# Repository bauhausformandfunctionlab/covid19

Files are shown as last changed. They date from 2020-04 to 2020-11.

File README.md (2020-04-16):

**Bauhaus Form + Function Lab**<br />
**Community Resources for COVID-19**<br />
**https://bffl.io**<br />

As the world works together to overcome the unprecedented challenges brought on by the COVID-19 pandemic, the team at the [Bauhaus Form + Function Lab](https://uni-weimar.de/bffl) is currently working with [partners and collaborators](http://bffl.io/partners) across the region and across Europe to share relevant designs and optimizations for personal hygiene equipment and other materials, which can be produced with the standard tools found in prototype labs, fablabs, makerspaces and individual studios in communities around the globe.

The Fine Print: We strongly urge everyone to adhere to the strictest hygiene measures and to consult with local authorities before beginning production or distribution. While these designs are being shared in good faith, the BFFL and Bauhaus-Universität Weimar do not guarantee the suitability for use, merchantability, or fitness for particular purpose of the designs listed below, and do not assume liability arising from their production or use. These designs are presented as research for individual experimentation and are not intended for production or use as medical products. The production and use of these designs is at your own risk. Please be aware that designs below are the property of their respective creators and are protected by various open source licenses. Feel free to share the resources linked here with other partners and institutions.

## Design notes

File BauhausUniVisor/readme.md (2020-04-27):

**Production Files for the BauhausUniVisor**<br />
Co-developed by Prof. Andreas Mühlenberend & Vertr.-Prof. Jason Reizner<br />
Production optimizations by Kristian Gohlke<br />
Bauhaus-Universität Weimar<br />
[https://bffl.io](https://bffl.io)

one material<br />
one process<br />
one minute<br />

#bauhausunivisor<br />
#oneminutevisor

This work is licensed under a [Creative Commons Attribution-NonCommercial-ShareAlike 4.0 International License](https://creativecommons.org/licenses/by-nc-sa/4.0/) and can be used for non-commercial purposes. Get in touch with the team if you would like to manufacture larger quantities under individual conditions.

**MAIN PRODUCTION FILE:**<br />
[BauhausUniVisor_2020_04_16_VARIANT_A_and_VARIANT_B_combined_NO_BRIDGES.pdf](https://github.com/bauhausformandfunctionlab/covid19/blob/master/BauhausUniVisor/BauhausUniVisor_2020_04_16_VARIANT_A_and_VARIANT_B_combined_NO_BRIDGES.pdf)

**PRINT these Files and distribute them with the Visors**<br />
Important Notes ('Beipackzettel', German):
[BauhausUniVisor_Beipackzettel_DE.pdf](https://github.com/bauhausformandfunctionlab/covid19/blob/master/BauhausUniVisor/BauhausUniVisor_Beipackzettel_DE.pdf)<br />
Assembly Instructions / Montageanleitung:
[BauhausUniVisor_Assembly_Guide.pdf](https://github.com/bauhausformandfunctionlab/covid19/blob/master/BauhausUniVisor/BauhausUniVisor_Assembly_Guide.pdf)

**Assembly Video:**<br />
The BauhausUniVisor - COVID19 laser cut face shield // One material, One process, One minute (https://www.youtube.com/watch?v=4FKMDfHXxKk)

**HINWEIS:** Visiere sind **kein** Ersatz für eine Mund-Nasenbedeckung!<br />
**NOTE:** Face Shield Visors are **not** a replacement for cloth face coverings or surgical face masks!  

This visor is intended to be produced from 0.5mm PETG film. In situations where PETG is not available, PET film can be substituted when sufficient surface quality and optical clarity can be guaranteed.

With sufficient laser power and optimization, one visor can be cut in one minute.

For flat PETG sheets coated with protective film, cutting in two passes is recommended using the highest speed and lowest power settings possible. We are currently cutting in two passes on a 120W Epilog CO2 system at 100s/70p/50f with power compensation enabled.

For PET material from the roll, cutting in a single pass using the provided templates marked 'with BRIDGES' will ensure correct registration of the work pieces. Since this material generally is not coated with protective film, it is recommended to remove cutting residue using alcohol.

On a low-cost 40W Lasercutter (tested on Beambox Pro) we have achieved good results with uncoated PET from a roll, cutting in a single pass at 30mm/sec and 63% Power.

When laser cutting PETG or PET, a sufficient exhaust extractor and filter system is necessary.

Preliminary tests indicate that PETG is resistant to disinfection agents including isopropyl alcohol, quaternary ammonium compounds and hydrogen peroxide solution. Note: PET/PETG components are *not* dishwasher safe.

We strongly urge everyone to adhere to the strictest hygiene measures and to consult with local authorities before beginning production or distribution. 

While this design is being shared in good faith, the Bauhaus Form + Function Lab and Bauhaus-Universität Weimar do not guarantee the suitability for use, merchantability, or fitness for particular purpose of the this visor, and do not assume liability arising from their production or use. This design is not intended for production or use as a medical device.

This work is licensed under a Creative Commons Attribution-NonCommercial-ShareAlike 4.0 International License.

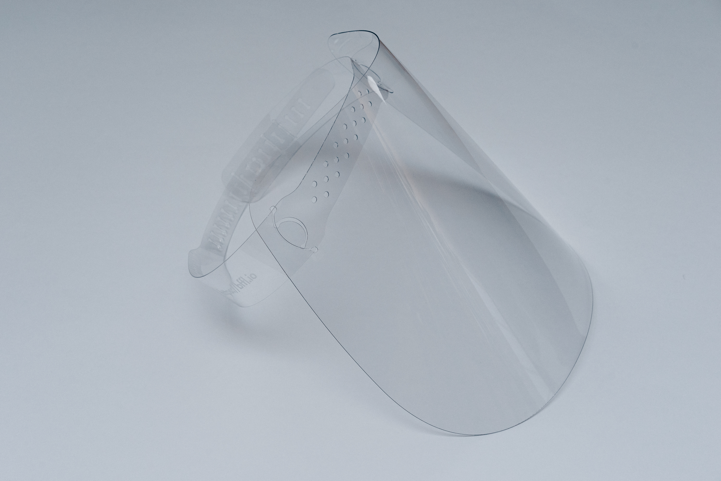
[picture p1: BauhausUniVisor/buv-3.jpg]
BauhausUniVisor


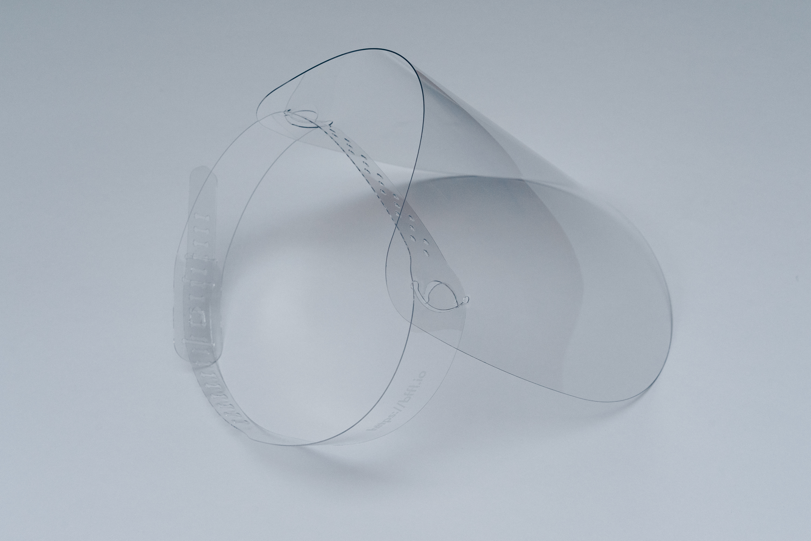
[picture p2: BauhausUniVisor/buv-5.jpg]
BauhausUniVisor


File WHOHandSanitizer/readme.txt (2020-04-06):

This is the directory for materials relating to the WHO Hand Sanitizer Formula.

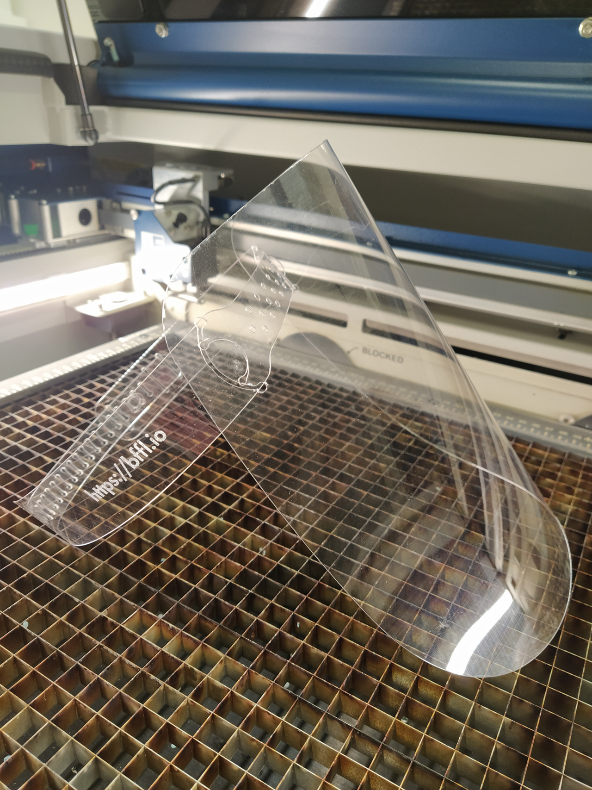
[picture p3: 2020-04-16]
BauhausUniVisor/BauhausUniVisor_Lasercut.jpg

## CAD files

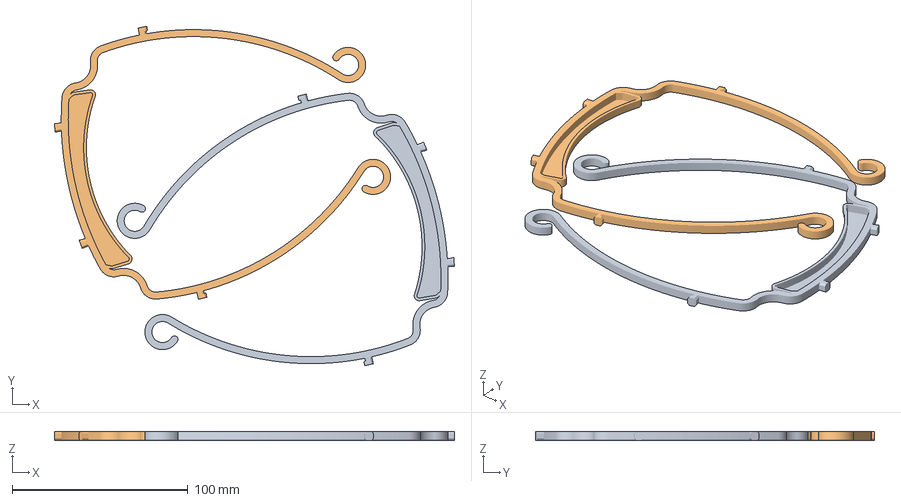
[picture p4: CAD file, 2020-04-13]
3DVerkstanVisor/2x_0.8_Visor_frame_EUROPE_ISO838_v3.3mf
227.4 x 193.0 x 5.00 mm
Visor_frame_EUROPE_ISO838_v3.stl x 2

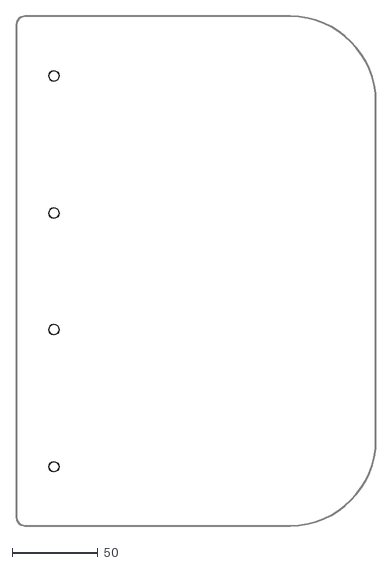
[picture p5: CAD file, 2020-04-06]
3DVerkstanVisor/ShieldTemplates/Lasercut-shield-EUROPE-ISO838-A6.dxf
210.0 x 297.0

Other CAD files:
alternative covid-19 production resources/3DVerkstanVisor/ShieldTemplates/Lasercut-shield-SWEDEN-A4.dxf
3DVerkstanVisor/ShieldTemplates/Lasercut-shield-SWEDEN-A4.dxf

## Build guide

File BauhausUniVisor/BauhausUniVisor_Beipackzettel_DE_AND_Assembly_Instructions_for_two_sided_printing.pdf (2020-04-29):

# BauhausUniVisor

# one material

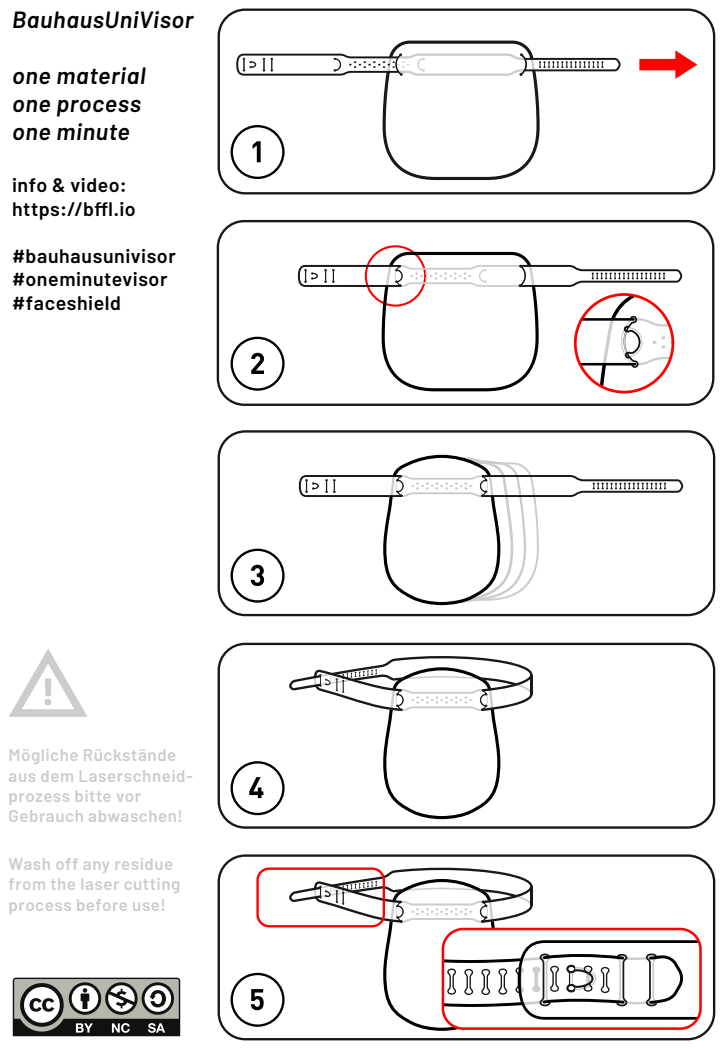
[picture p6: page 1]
one process one minute; info & video: https://b.io; #bauhausunivisor #oneminutevisor #faceshield

Mögliche Rückstände
aus dem Laserschneid-
prozess bitte vor
Gebrauch abwaschen!

Wash off any residue
from the laser cutting
process before use!

Bauhaus-Universität Weimar Fakultät Kunst & Gestaltung Bauhaus Form + Function Lab (BFFL) https://bffl.io/de/

## BauhausUniVisor – eine Fabrikationsstudie in Zeiten von Covid-19

one material
one process
one minute

Die beiliegenden Visiere wurden von Prof. Andreas Mühlenberend (https://www.uni-weimar.de/en/art-and-design/structure/disciplines-staff/produktdesign-product-design/prof-andreas-muehlenberend/) und Vertr.-Prof. Jason Reizner (https://www.uni-weimar.de/de/kunst-und-gestaltung/professuren/interface-design/) gemeinsam entwickelt und in Zusammenarbeit mit Kristian Gohlke (https://www.uni-weimar.de/de/kunst-und-gestaltung/struktur/lehrgebiete-personen/produktdesign/kristian-gohlke-msc-digital-media/) für die Produktion optimiert.
Sie bestehen aus einem einzigen Material (transparenter 0,5mm PET- oder PETG-Film) und können auf den Lasercuttern der Bauhaus-Universität Weimar hergestellt werden.

Kontaktdaten für Kommentare und Rückfragen, eine Montageanleitung sowie die Produktionsdateien und Hinweise zur eigenen Herstellung sind unter der Adresse https://bffl.io/de/ abrufbar.

Wir möchten uns mit diesem kleinen Beitrag für Ihren Einsatz bedanken!

Als universelles Design („one size fits all“) kommt das BauhausUniVisor ohne Teile aus dem 3D-Drucker oder zusätzliche Gummibänder aus. Der Produktionsdurchsatz ist im Vergleich zu 3D-Druck Varianten wesentlich höher und gewährleistet eine maximale Ausnutzung des Materials: Acht Visiere können aus einer 1000x600mm großen PETG-Folie in weniger als fünf Minuten geschnitten werden. Darüber hinaus ist der Entwurf prinzipiell auch für die Produktion in Roll-to-Roll Prozessen geeignet.
Vorläufige Tests zeigen, dass PETG gegen Desinfektionsmittel wie Isopropylalkohol, quaternäre Ammoniumverbindungen und Wasserstoffperoxidlösung beständig ist. Die Reinigung der Visiere vor Gebrauch wird empfohlen, u.a. auch zur Entfernung von Rückständen aus dem Laserschneidprozess.

Senden Sie uns Ihre Fotos mit dem Visier (gerne auch Selfies) per Email oder teilen Sie ihre Bilder auf Social-Media-Kanälen unter Angabe des Hashtags #bauhausunivisor und dem Link https://bffl.io/de/

Das Kleingedruckte:
Wir fordern nachdrücklich alle dazu auf, die von Behörden, Betrieben und Mitmenschen empfohlenen Hygienemaßnahmen strengstens einzuhalten! Visiere sind kein Ersatz für eine Mund-Nasenbedeckung!

Obwohl die Entwürfe mit bestem Wissen und Gewissen weitergegeben werden, garantieren das BFFL und die Bauhaus-Universität Weimar nicht die Gebrauchstauglichkeit, Marktgängigkeit oder Eignung für einen bestimmten Zweck und übernehmen keine Haftung, die sich aus ihrer Herstellung oder Verwendung ergibt. Insbesondere stellen die Entwürfe als Studien zur individuellen Erprobung der Fabrikation explizit keine Medizinprodukte dar. Jegliche Nutzung oder sonstiger Gebrauch erfolgt auf eigene Gefahr durch die Nutzer. Bitte beraten Sie sich vor Beginn der Produktion und der Verteilung von Material auch mit den örtlichen Behörden und Institutionen.

Selbermachen? Gerne! Unterstützen Sie die Produktion!
Die Produktionsdateien sind auf https://bffl.io/de/ bereitgestellt und lizensiert für die Verwendung unter den Bedingungen der Creative Commons Attribution-NonCommercial-ShareAlike 4.0 License: (http://creativecommons.org/licenses/by-nc-sa/4.0/) https://creativecommons.org/licenses/by-nc-sa/4.0/deed.de

Bitte beachten Sie:
Das Design ist unter einer Open-Source Lizenz urheberrechtlich geschützt und darf nur unter den jeweiligen Lizenzbedingungen verbreitet und hergestellt werden. Für weitergehende Anfragen nehmen Sie bitte Kontakt mit uns auf.

Bitte informieren Sie Betriebe, Zulieferer und Institutionen die über entsprechende Produktionsmittel oder Distributionskanäle verfügen über diese Initiative. Jeder Beitrag zählt.

HYGIENE - Ein Gebot der Höflichkeit!

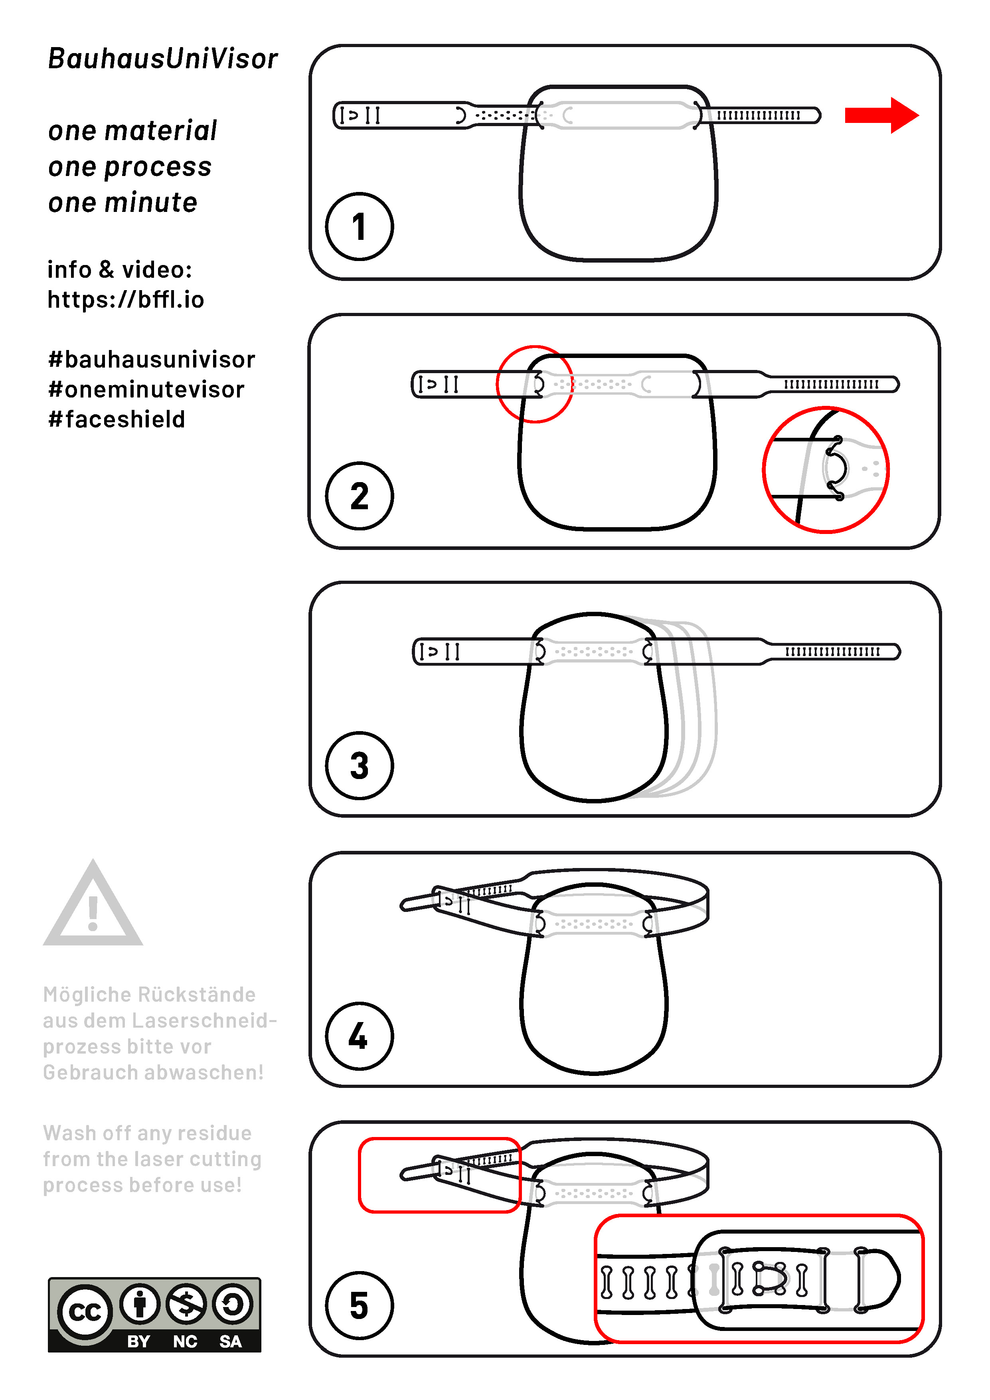
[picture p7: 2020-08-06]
BauhausUniVisor/BauhausUniVisor_Assembly_Guide.jpg

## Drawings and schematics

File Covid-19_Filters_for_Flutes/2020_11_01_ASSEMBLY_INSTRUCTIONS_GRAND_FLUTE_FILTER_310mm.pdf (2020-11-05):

# MONTAGE / ASSEMBLY: FILTER GROßE FLÖTE / GRAND FLUTE

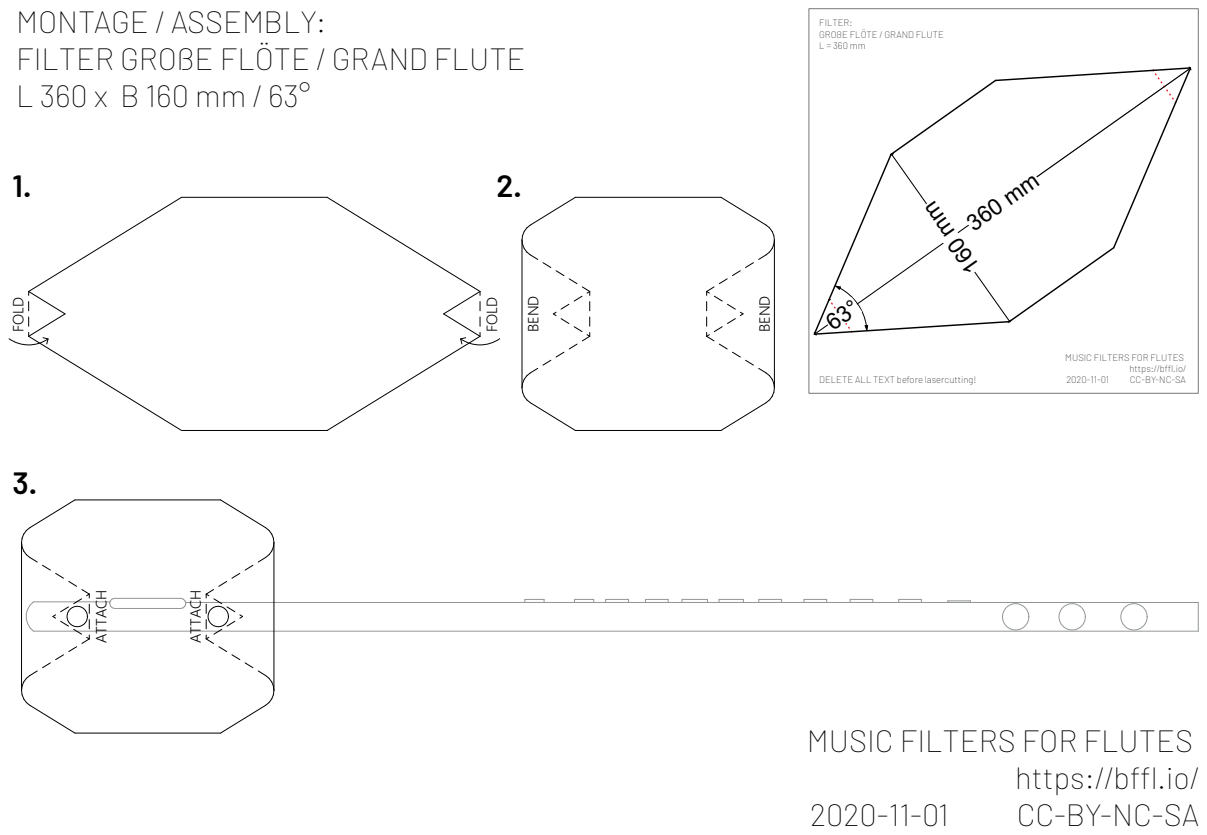
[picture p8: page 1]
https://b.io/; FOL; BEN; ATTAC

FILTER:
GROßE FLÖTE / GRAND FLUTE

MUSIC FILTERS FOR FLUTES

DELETE ALL TEXT before lasercutting!

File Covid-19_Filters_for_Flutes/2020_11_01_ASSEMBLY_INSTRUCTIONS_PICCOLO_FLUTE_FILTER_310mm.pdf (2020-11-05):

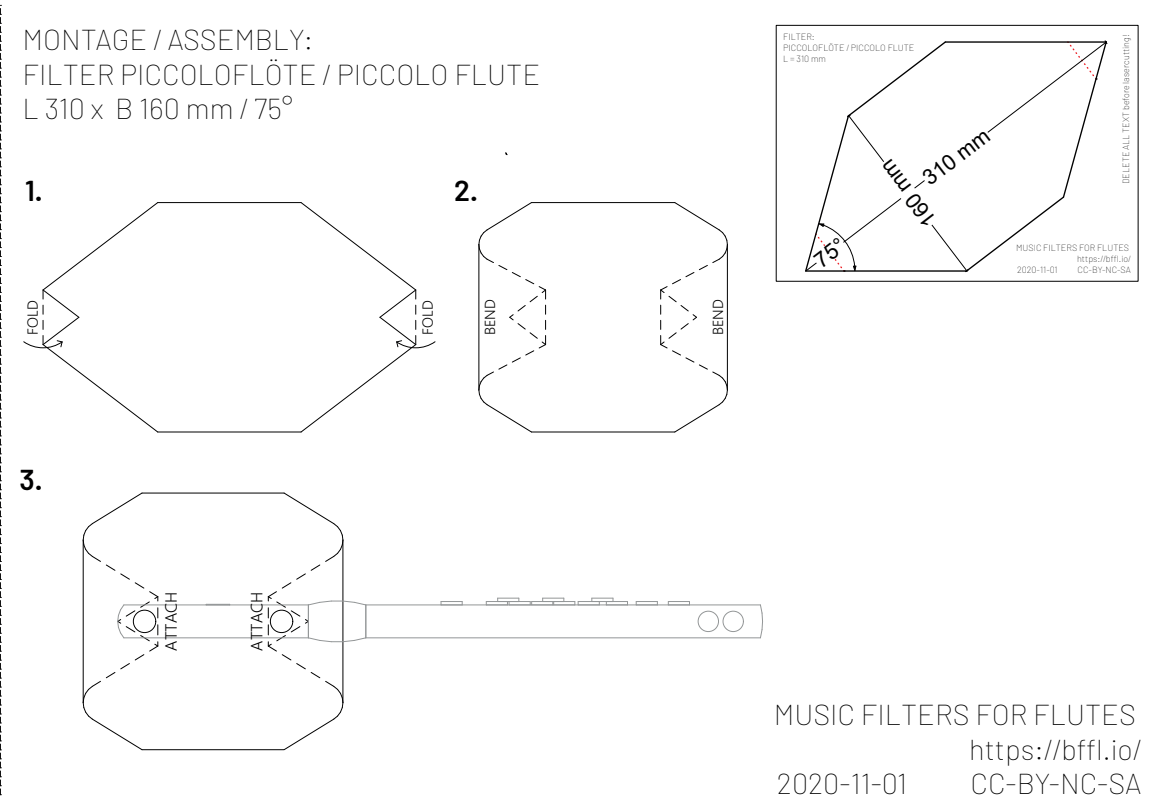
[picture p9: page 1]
https://b.io/; FOL; 1. 2. ATTAC; ATTAC; BEN

MONTAGE / ASSEMBLY:
FILTER PICCOLOFLÖTE / PICCOLO FLUTE

FILTER:
PICCOLOFLÖTE / PICCOLO FLUTE

DELETE ALL TEXT before lasercutting!

MUSIC FILTERS FOR FLUTES

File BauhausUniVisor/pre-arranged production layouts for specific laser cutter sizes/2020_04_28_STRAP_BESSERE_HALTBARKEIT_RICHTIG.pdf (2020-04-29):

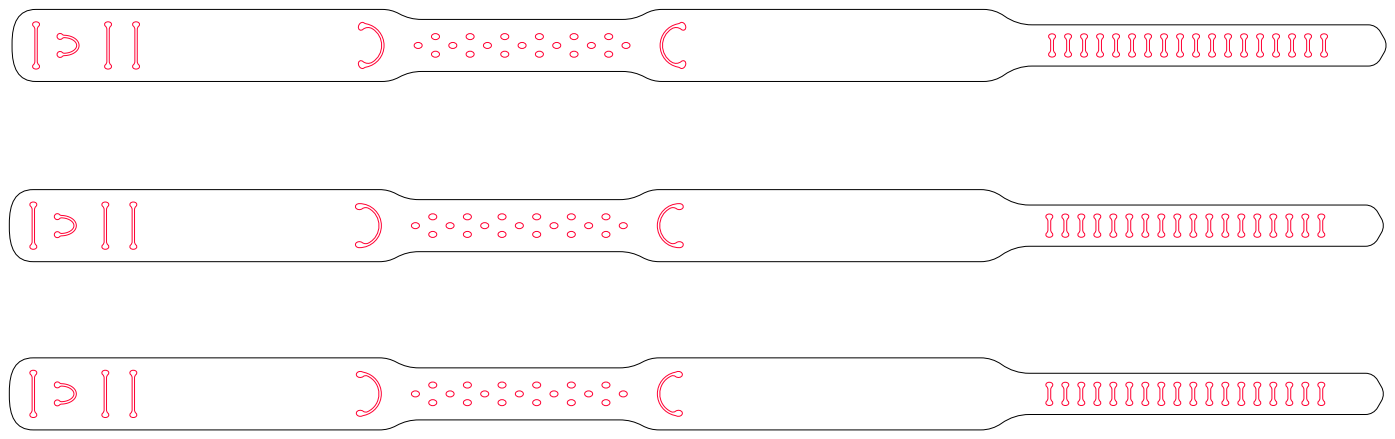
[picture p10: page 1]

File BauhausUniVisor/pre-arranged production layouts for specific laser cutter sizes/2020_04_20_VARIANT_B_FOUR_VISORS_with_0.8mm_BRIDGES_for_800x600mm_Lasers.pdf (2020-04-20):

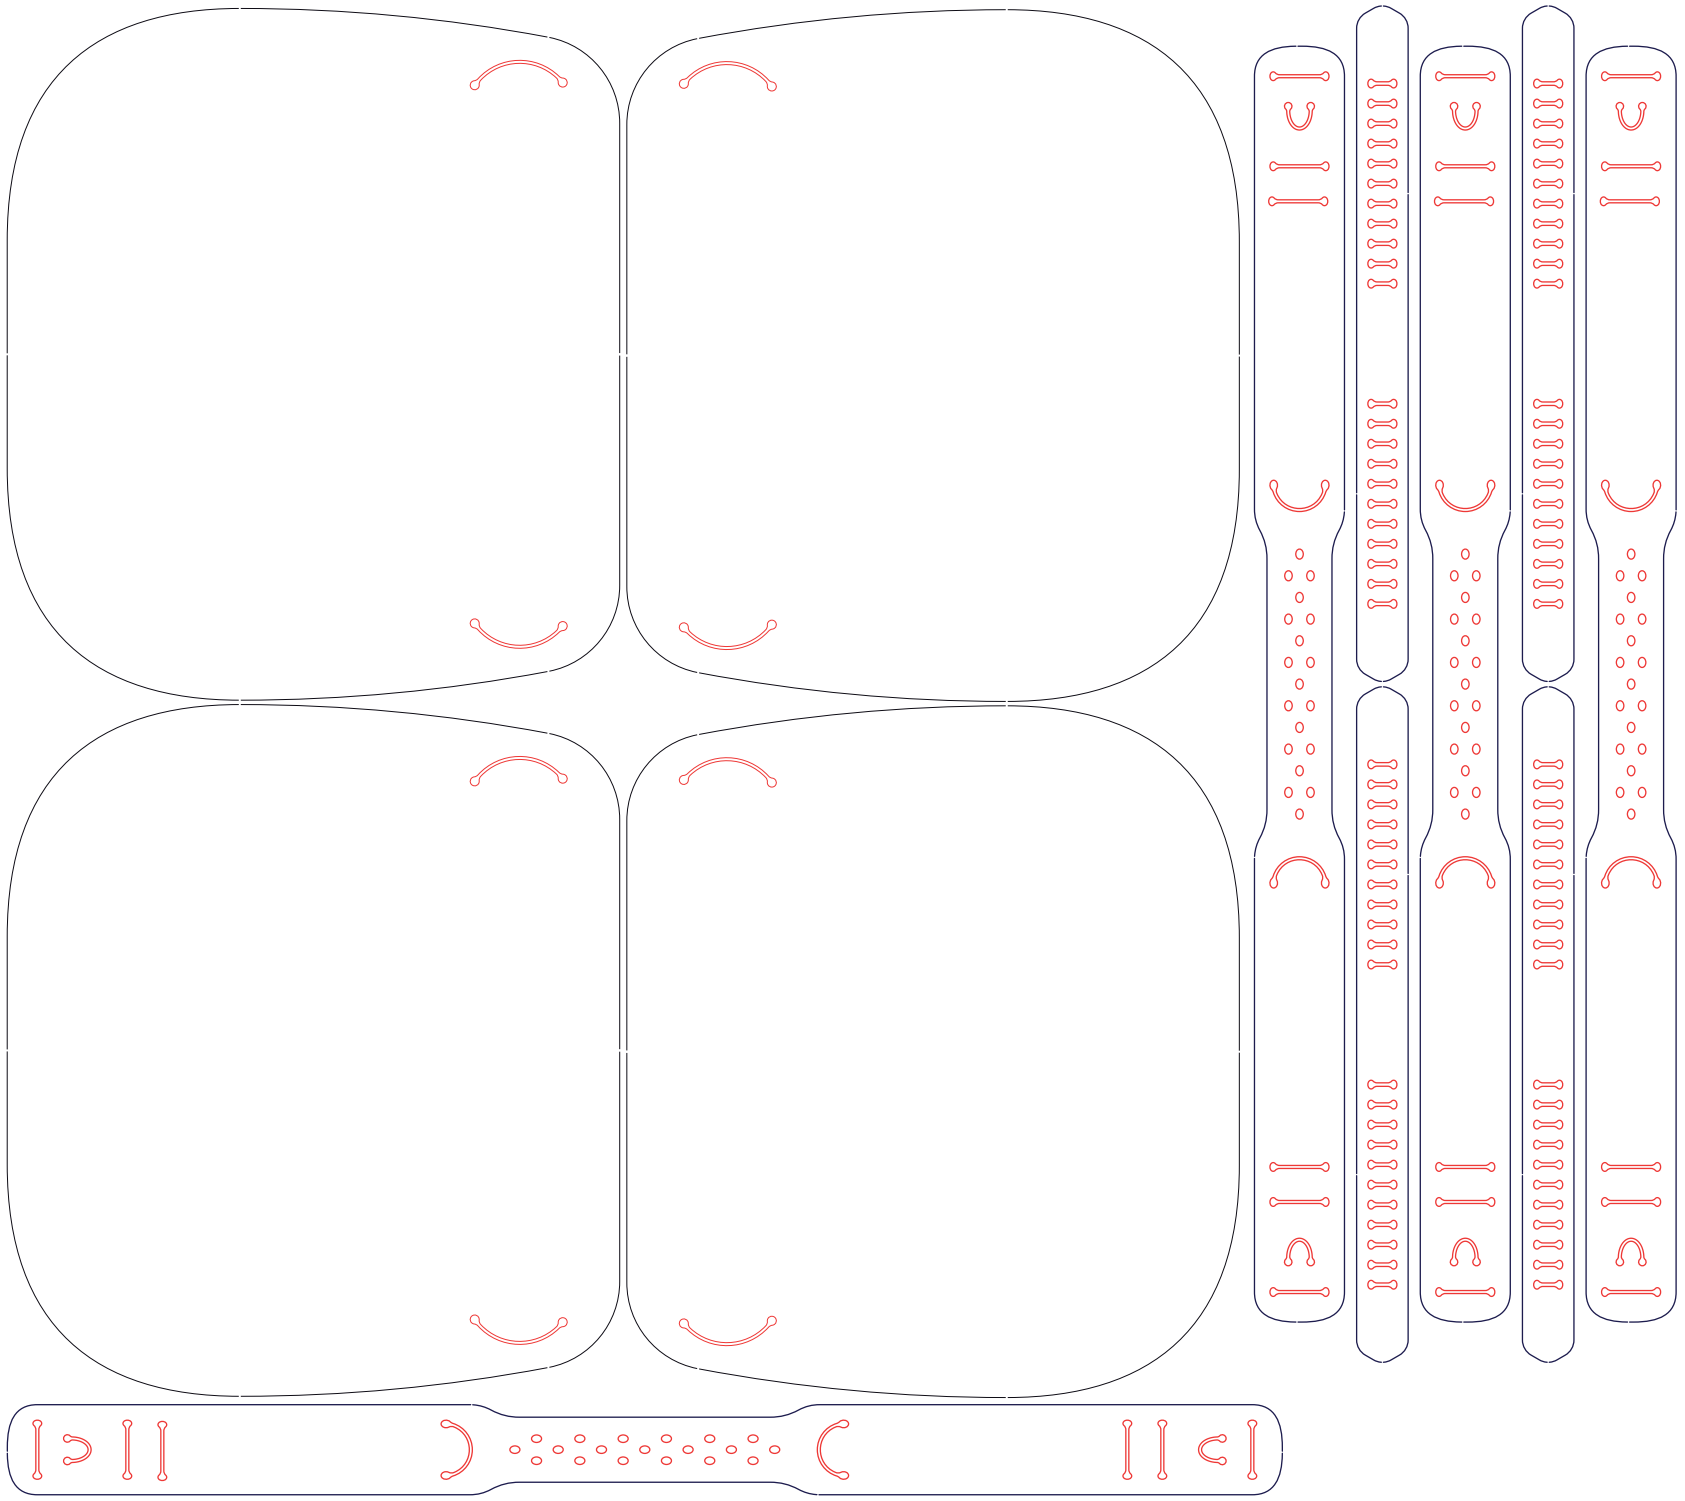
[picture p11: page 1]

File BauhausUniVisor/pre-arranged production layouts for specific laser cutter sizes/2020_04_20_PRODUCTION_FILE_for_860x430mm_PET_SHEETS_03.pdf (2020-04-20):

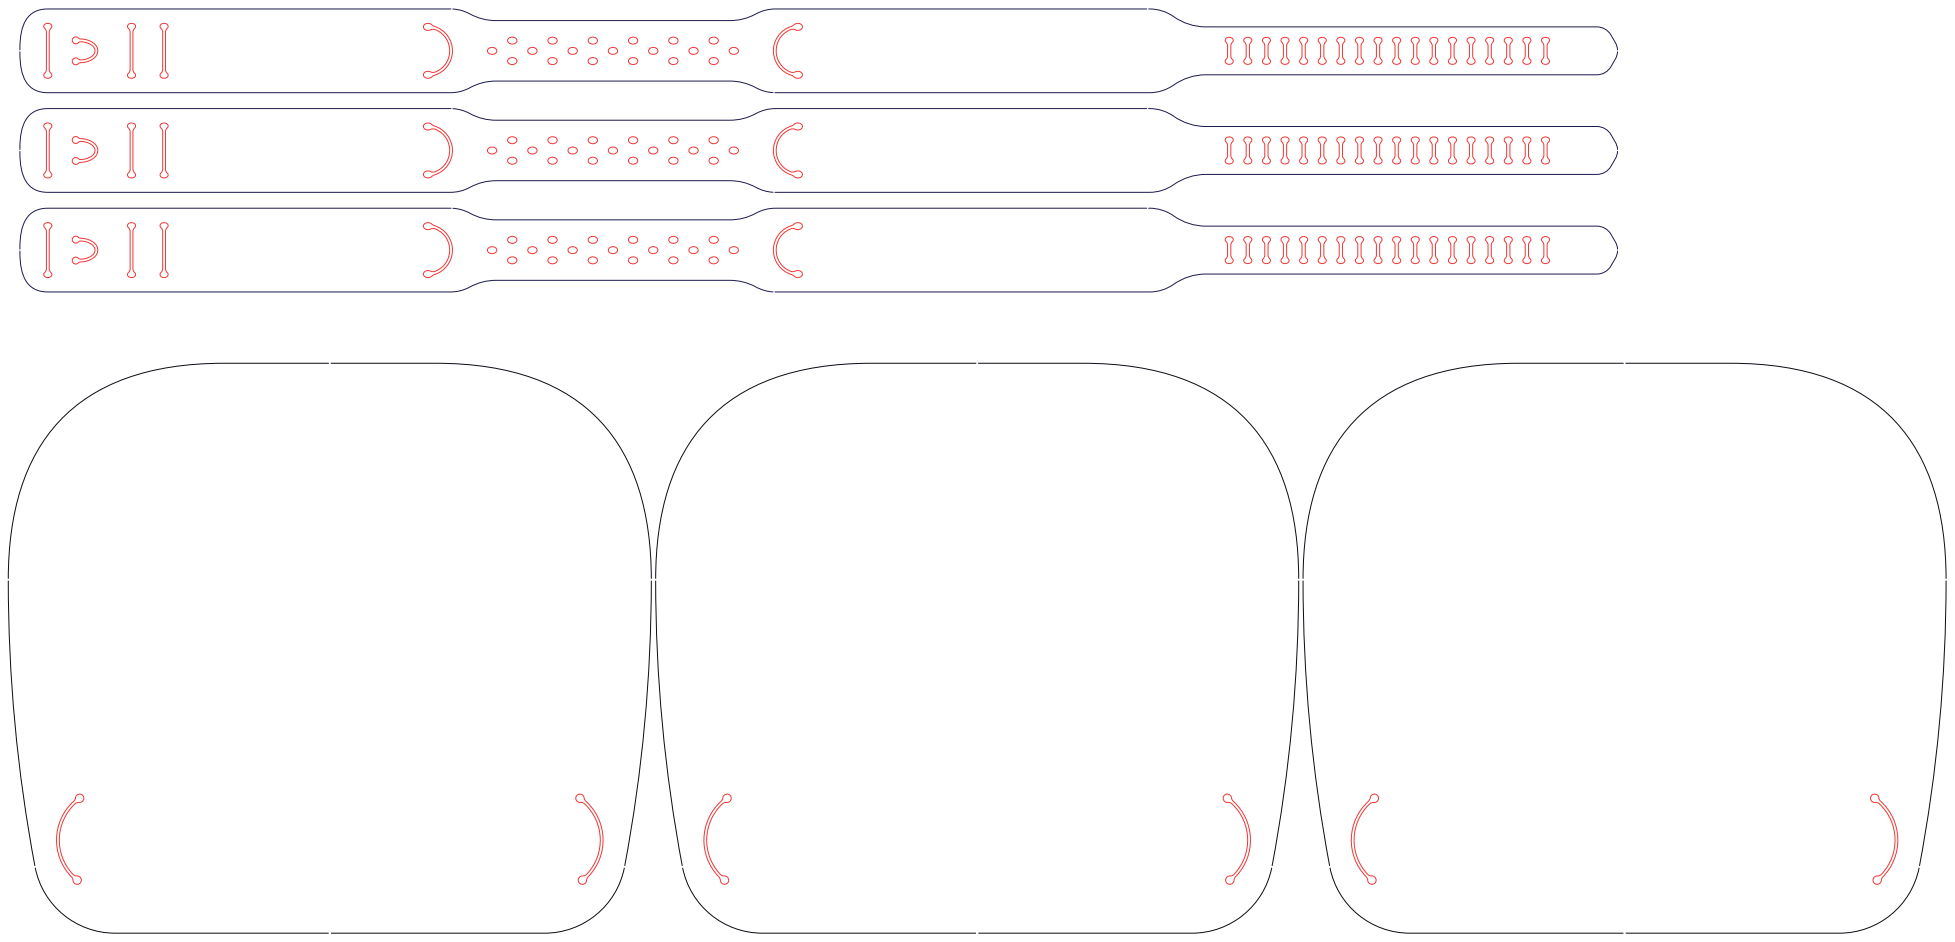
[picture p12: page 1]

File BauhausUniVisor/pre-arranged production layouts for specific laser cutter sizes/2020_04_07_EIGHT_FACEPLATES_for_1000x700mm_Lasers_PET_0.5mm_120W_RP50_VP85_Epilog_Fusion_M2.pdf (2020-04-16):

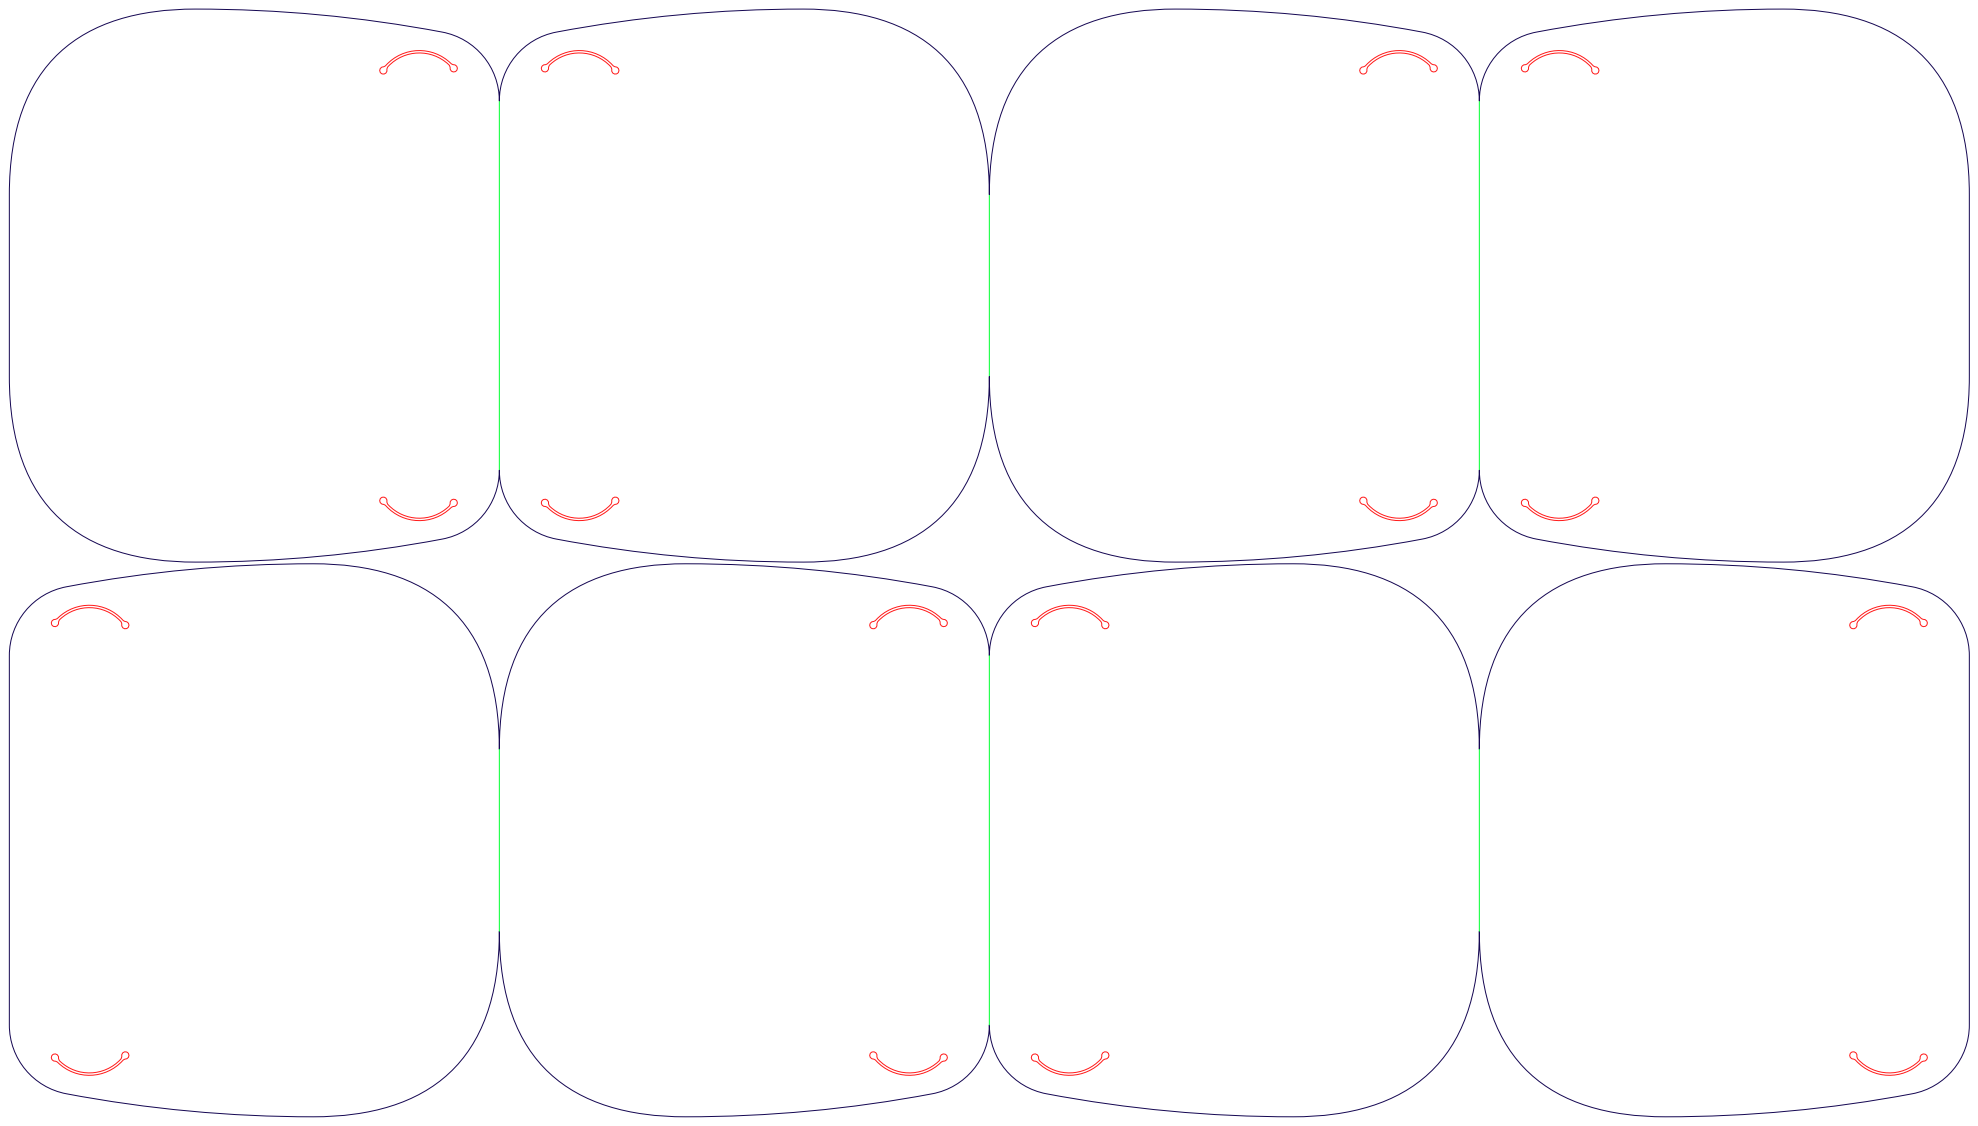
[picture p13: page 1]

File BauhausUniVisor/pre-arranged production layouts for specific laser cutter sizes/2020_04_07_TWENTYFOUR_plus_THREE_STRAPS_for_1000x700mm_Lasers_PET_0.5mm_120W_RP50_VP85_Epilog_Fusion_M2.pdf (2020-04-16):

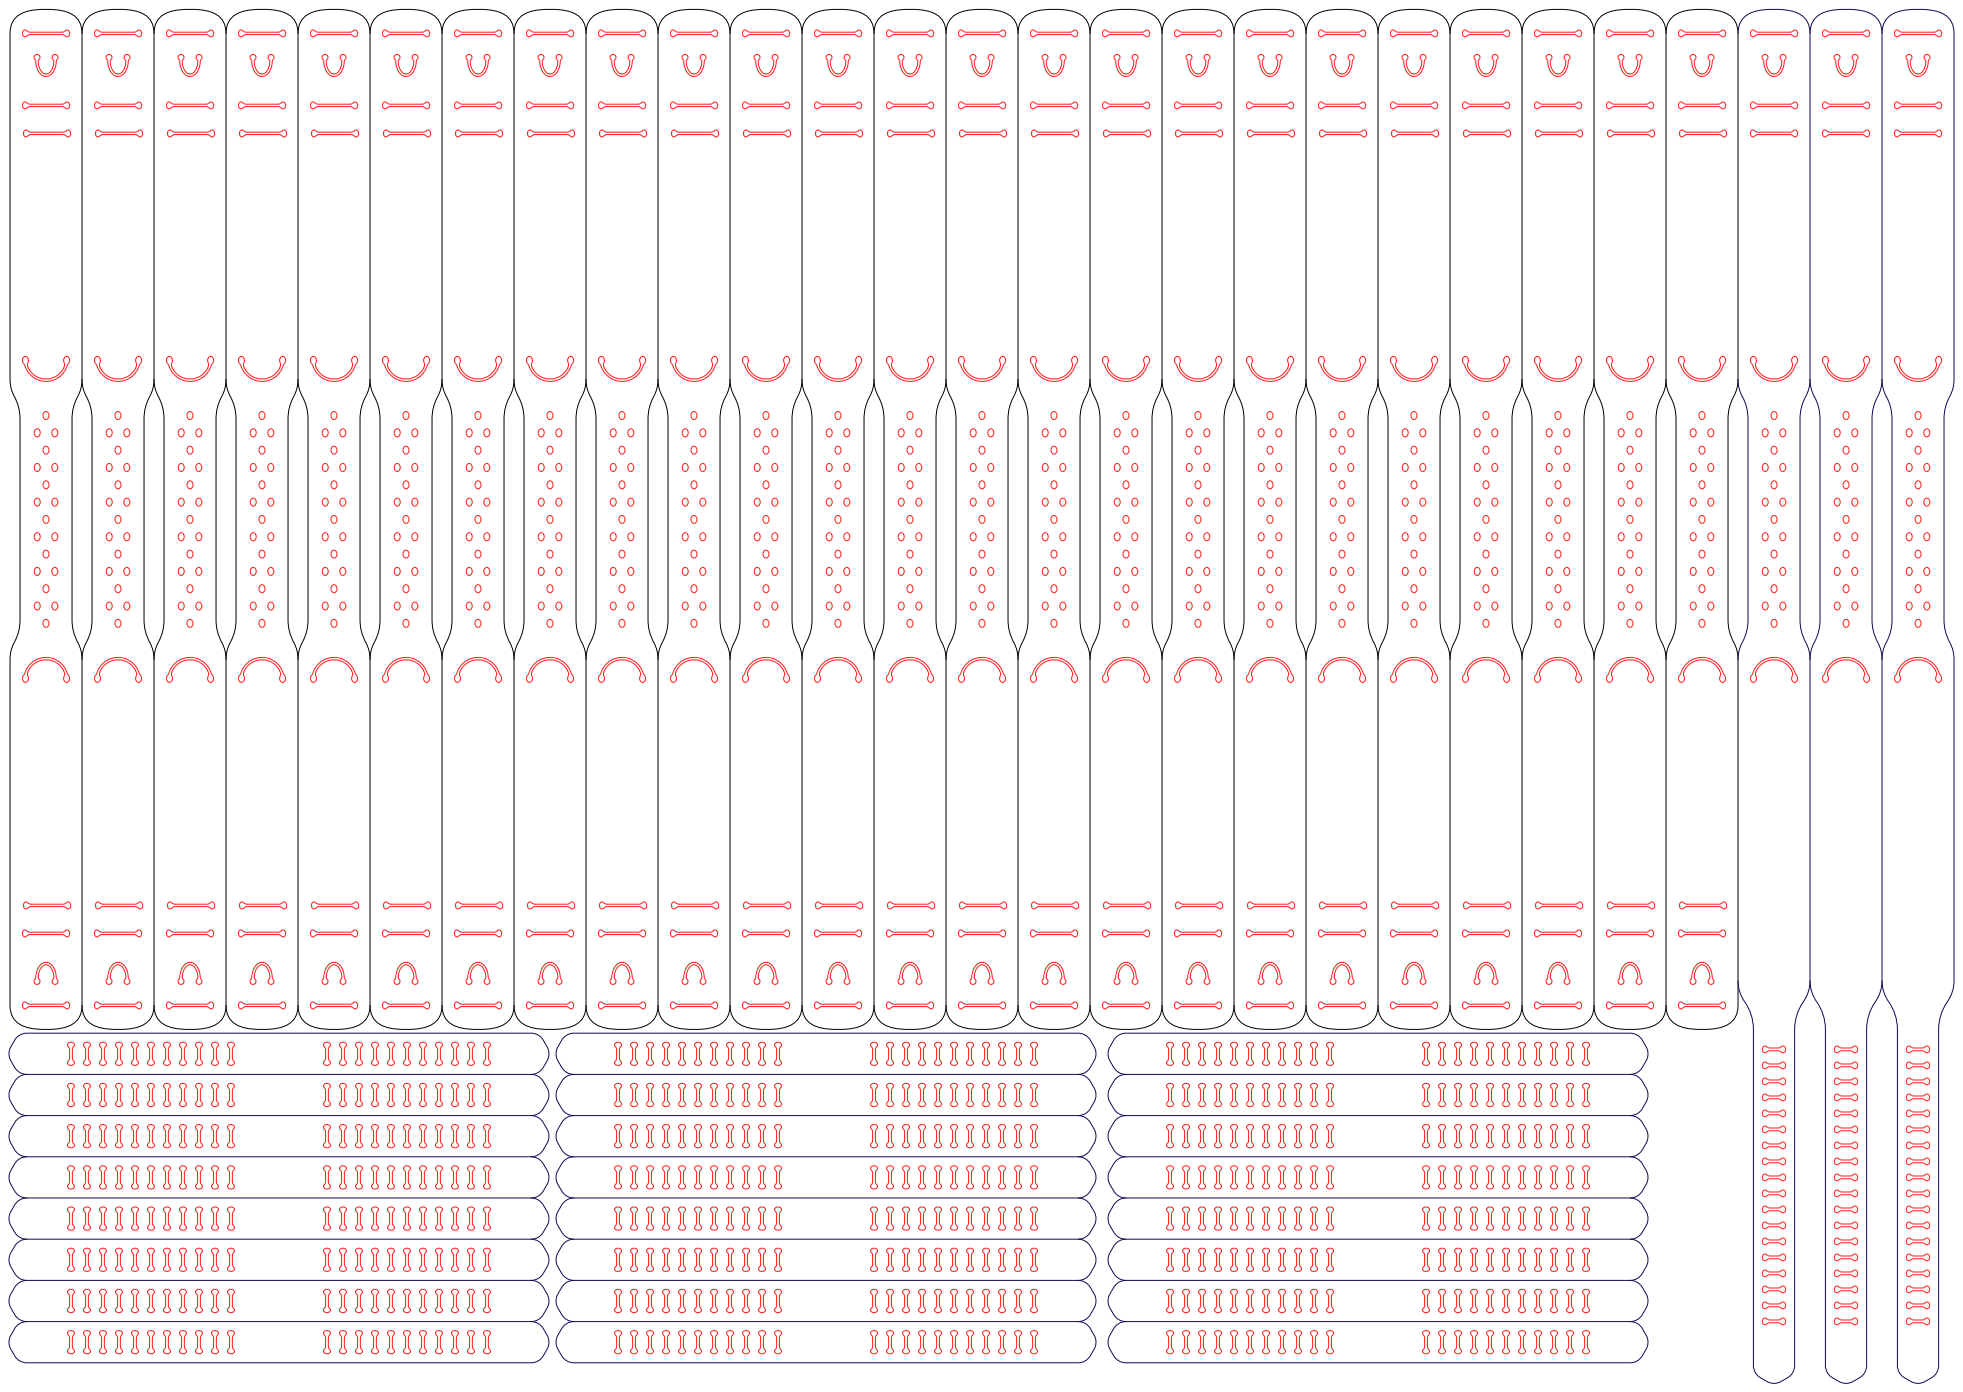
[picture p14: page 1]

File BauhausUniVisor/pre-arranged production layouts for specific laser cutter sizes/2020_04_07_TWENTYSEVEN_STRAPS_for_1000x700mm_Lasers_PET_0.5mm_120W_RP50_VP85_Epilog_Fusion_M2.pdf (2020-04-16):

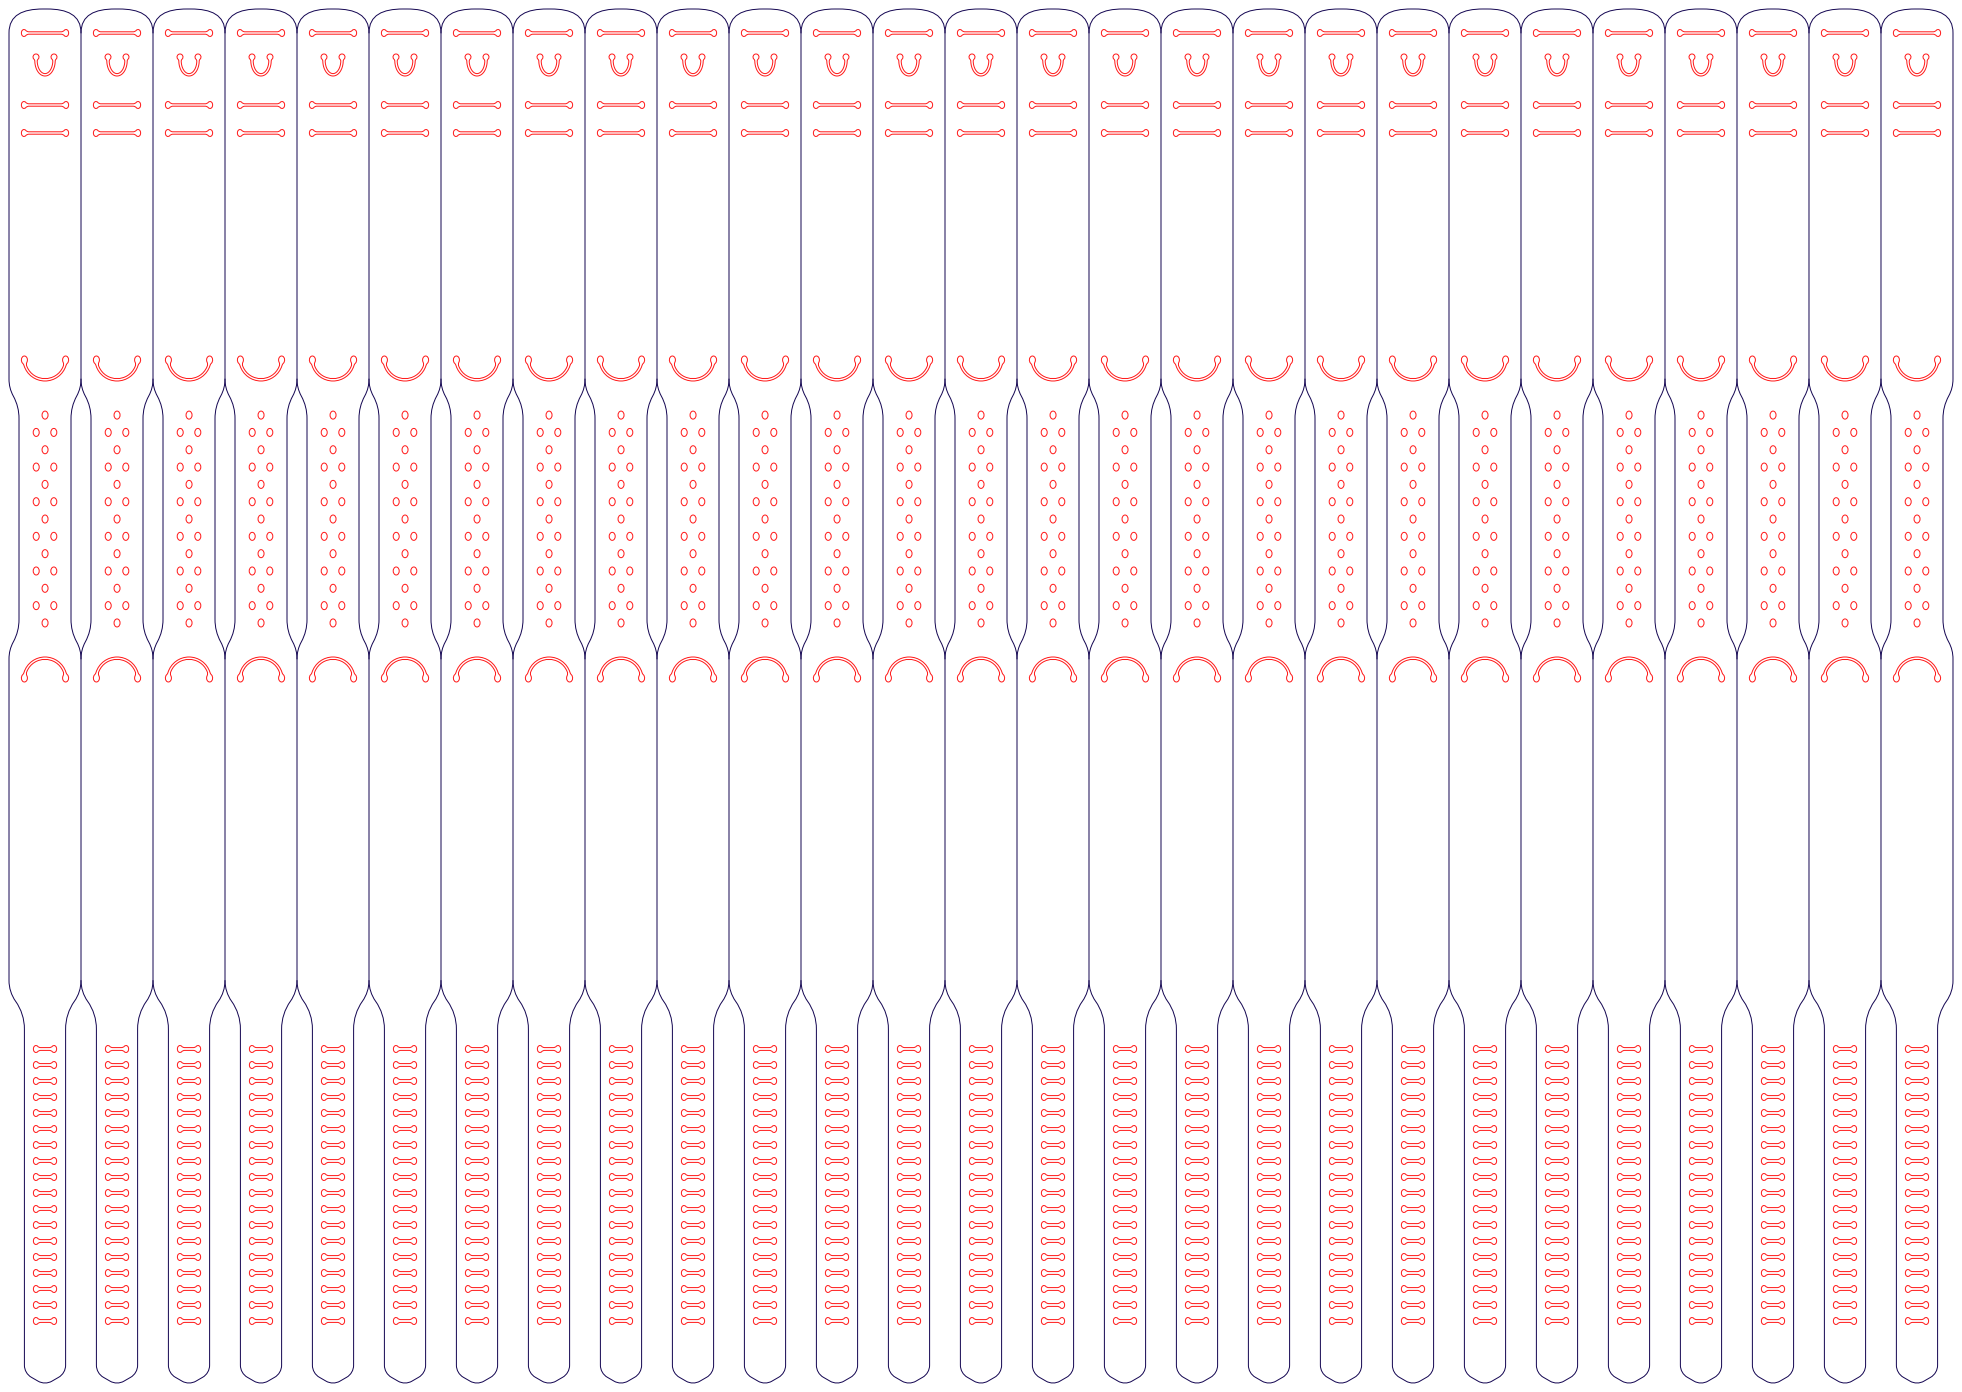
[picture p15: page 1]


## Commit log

2020-04-06 Create BFFL-LaserCutVisor
2020-04-13 updated filenames
    [Lasercut-shield-SWEDEN-A4.dxf]
2020-04-16 major cleanup
    - meaningful filenames
    - self-explanatory file content
    - added/cleaned up lasercutter specific production files
    - moved alternative resources to their own folder
    - two main lasercut files (no bridged and 0.8mm bridges) are now at the root of BauhausUniVisor folder
    [2x_0.8_Visor_frame_EUROPE_ISO838_v3.3mf, Lasercut-shield-EUROPE-ISO838-A6.dxf, Lasercut-shield-SWEDEN-A4.dxf]
2020-04-19 fixed broken dependencies
    [2x_0.8_Visor_frame_EUROPE_ISO838_v3.3mf, Lasercut-shield-EUROPE-ISO838-A6.dxf, Lasercut-shield-SWEDEN-A4.dxf]
2020-04-20 production file for medium quality PET Roll material
2020-04-20 production files for lasercutters
2020-04-20 modified production layout for medium quality 430mm PET roll material
2020-04-20 for 800x600mm lasers
2020-04-20 added layout for 800x600mm laser
2020-04-20 updated assembly instructions
2020-04-22 Beipackzettel and Assembly Instructions combined for double sided printing
2020-04-27 PRINT THIS and distribute with product!
2020-04-29 latest iteration of the one-piece straps with minor improvement
2020-04-29 updated visual assembly instructions
2020-08-06 Filter Designs for Brass Instruments
2020-08-06 Filters for Brass Instruments
2020-09-08 Updated Brass Filter Designs
2020-09-08 Removed deprecated filter designs
